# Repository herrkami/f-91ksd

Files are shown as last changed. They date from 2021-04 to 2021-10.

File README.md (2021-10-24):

# F-91KSD

F-91KSD is a functional and optical modification of the Casio® F-91W.

**Hardware and firmware are heavily based on the brilliant
[pluto](https://github.com/carrotIndustries/pluto) project.**

## Features
- Multiple chainable countdown timers
- Multiple alarms
- Pulsar app: tap button to measure BPMs and define LED animation
- Consistent and direct user interface
- Three bright LEDs for better readability, blinkiness, and silent alarms
- Stopwatch
- RTTTL ringtones for alarm sounds including some custom sci/fi sounds
- Extensive customisation (key beep frequency and duration, etc.)
- Watch can be calibrated (drift < 1s per month)
- Displays time in decimal/binary/hexadecimal base
- greater than 1 year battery life (estimate based on current consumption)

## Differences to [pluto](https://github.com/carrotIndustries/pluto)
- New PCB (designed in Eagle)
- No compass, no IR receiver, no OTP generation
- Three LEDs including a flash light
- Different menu structure (more Casio-oriented, less menu diving)
- Chainable countdowns
- Optical alarms
- BPM measurement and optical/acoustical metronome
- Some minor bug fixes

## In progress
Battery monitoring isn't functional yet. 

# Credits
Without previous work by [carrotIndustries](https://github.com/carrotIndustries/) and [sh-ow](https://github.com/sh-ow) this project wouldn't exist.
Most of the software components are their work.

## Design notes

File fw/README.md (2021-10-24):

# F-91KSD Firmware
The F-91KSD firmware is based on the [pluto firmware](https://github.com/carrotIndustries/pluto-fw).
It has been forked from its [May 11, 2018 commit state](https://github.com/carrotIndustries/pluto-fw/commit/a3063225761d98f1a0111b59fe00d9e4cfaac7c2).

## Assisted calibration
Aside from being a cool nerd gadget pluto's main purpose is accurately
telling the time. To do so, the RTC needs to be calibrated to
compensate for the crystal's error. To simplify this, the
firmware can now assist the user by keeping track of how long it's been
since the time has last been set. The process goes like this (`acal` in
the time menu):

- **ME**asure: press enter when the minute changs on the reference clock, the time difference will be shown
- **S**econds since **L**ast set: shows how long it's been since the time has been set in units of 100 seconds
- P**PM**: shows the calculated deviation in units of 10ppb, may display "over" when the valued exceeds the displayable range
- **CAL**ibration **st**ore: takes the calculated ppm value, subtracts it from the current calibration value and updates the calibration
- **ADJ**ust: corrects the time by the measured value. Correction only takes place when the correction value can be applied without overflow, PM flashed while correction is pending.

# Architectural overview
To simplify development, the pluto firmware can be compiled to run on
Linux. User interface (LCD screen and buttons) is provided by a Gtk+
application the firmware connects to using a pair of ZeroMQ sockets. In
spite of being technically inaccurate, this mode of operation is called
'simulator'.
This requires dividing the firmware in three layers:

## Hardware Abstraction Layer (hal)
This layer provides the interface to the underlying hardware. Currently, there are HALs for
the MSP430FR6972 target and the simulator running on Linux. Only the hardware-dependent aspects
are implemented here, the hardware-independent aspects are left to the
next layer to avoid code duplication.

## Services (svc)
The services layer implements hardware-independent features like
playing back RTTTL ringtones, providing the LCD character set and
handling menu operation.

## Application (app)
The application layer provides the user interface. Currently, the
application layer is dependent on the F-91W's LCD layout.

# Simulator
As explained earlier, the firmware can be compiled to run on Linux.
This way, the firmware has been developed before the hardware being
available. Not having to fiddle with the tiny watch hardware makes
development of target-independent features much easier as well. To
simplify debugging of the firmware, the user interface consisting of the LCD screen and
buttons runs as a separate process the firmware connects to using a
pair of ZeroMQ sockets. The buzzer is emulated inside of the firmware
itself using a direct digital synthesis approach. To make the emulated
buzzer sound more real, the DDS lookup is rich of odd and even
harmonics. Sound is output using pulseaudio. Primarily due to laziness,
the emulator doesn't support these features :

- setting time/date
- RTC calibration
- persistent settings
- non-constant compass values
- backlight dimming

This list is very likely to be incomplete, nevertheless the simulator
has proven to be quite useful. Obligatory screenshot:
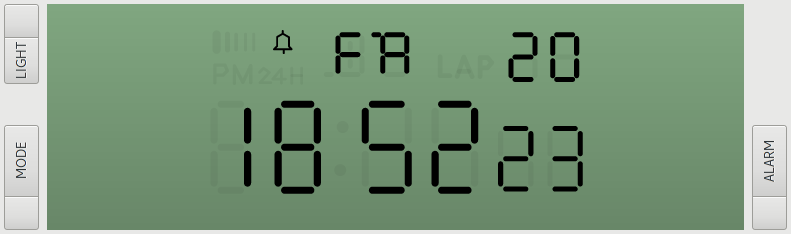
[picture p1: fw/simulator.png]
Simulator GUI


# Target
To conserve power and get anywhere near an acceptable battery life, the
firmware has to make aggressive use of the MSP430 low power features.
Most of the time, the MCU is asleep in LPM3 mode. In this mode, only
the low-frequency clock ACLK (sourced from 32.768 kHz crystal) and
low-power peripherals, like LCD and RTC are active. The MCU gets woken
up by interrupts:

- RTC as 4Hz tick source, used for display updating and time
  base for countdown timers.
- ~100Hz debounce timer: This timer only runs, when the aforementioned
  button polling ISR detects a pressed button.
- 128Hz AUX timer: This timer gets enabled by the services when there's
  need for high-precision timing of events like RTTTL playback or the
  stopwatch.
- 16Hz timer interrupt for button polling: Because of layout
  constraints, the buttons aren't connected to interrupt-capable GPIO
  pins, so this interrupt is used. Since the associated interrupt
  service routine only checks for the state of three GPIO pins, and
  quickly goes back to sleep, its power footprint is negligible.

All ISRs except for the last one exit the low-power mode, so the main
loop will get called.

# Detailed architecture
## HAL
The HAL provides a unified interface to the target's and simulator's
features:
### LCD
The HAL groups the LCD into digits. A digit is either a
7-segment-like digit or a bunch of indicators.
The simulator's HAL sends the segments to be set over to the display
process as a ZeroMQ message. The target has has to use a mapping table
that maps HAL LCD segments to the appropriate COM and SEG lines.
### Other features
The remaining features are pretty mundane, in case you want to
implement a new hal, take a look at common/hal/hal.h to find out what
you need to implement.

## Events
To meet above power requirements, the pluto firmware is event-based.
Once the main loop gets called, it figures out why it's been called and
populates a bitfield typed `svc_main_proc_event_t` accordingly and
hands over to `svc_main_proc`. After handling services-related things
like processing alarms and countdown timers, it'll dispatch the event
to the currently active app.

## Apps, Views and Menus
An app provides a distinct set of features to the users. It doesn't contain any
business logic, that's what the services are for. An app is divided
into multiple views. A view is roughly equivalent to one level in menu
hierarchy. A view's main function may either just call the menu in case
the view offers a constant number of choices to the user or may handle
events and drawing all by itself when more complex interaction is
required. Aside from a list of items, the menu provides a facility for
handling numeric input. To accommodate different use cases, the menu
relies on the application to translate incrementing and decrementing a
single digit into an actual numeric value taking into account clipping
and other constraints.

## LCD
The services layer uses a character table for each kind of LCD digit to
provide the best possible character rendering for each segment. It
provides functions for writing strings and integers to the LCD.

## OTP generation
Right now, the OTP generator is WIP, since there isn't a way to
synchronize the OTP clock and uploading secrets involves taking apart
the watch and flashing the firmware. To protect the OTP secrets,
they're encrypted using the MSP430's built-in AES peripheral. The
key is derived from the 4-digit PIN using the first 128bits of the
PIN's SHA-1 hash. One has to take care to pad the secrets with random
bytes, so that an attacker can't tell whether a PIN is correct or not.
You're welcome to improve the security of the secret storage.

## Persistent settings
Since the MSP430FR6972 uses FRAM for nonvolatile storage, writing
nonvolatile data is as easy as writing to RAM. All nonvolatile
variables are linked into a dedicated section, that can be left
unmodified when updating the firmware. That's what the "program-noload"
target is for. Currently, alarms, countdown timers, OTP secrets and
some settings are stored in nonvolatile memory.

# How do I build?
## Dependencies for both target and simulator
 - python 3 (3.5 tested)
 - python-rtttl for parsing RTTTL ringtones
 - make

## Dependencies for simulator
 - C compiler (gcc tested)
 - zeromq (for communication between firmware and GUI)
 - pulseaudio (for buzzer simulation)
 - mbedtls (for simulating the MSP430's hardware AES)
 - python (GUI)
 - Gtk+ 3 (GUI)
 - pygobject (GUI)

## Dependencies for target
 - msp430-elf toolchain
 - mspdebug for firmware programming

With these dependencies satisfied, the pluto firmware should build on
any reasonably up-to-date Linux distribution.

## Building and running simulator
```
$ cd sim
$ make
$ ./emu.py&
$ ./sim
```

## Building for target
```
$ cd target
$ make
$ make program
```
You may have to modify the Makefile to suit your particular programmer.

# Credits
Without previous work by [carrotIndustries](https://github.com/carrotIndustries/) and [sh-ow](https://github.com/sh-ow) this project wouldn't exist.
Most of the software components is their work.

# Included third-party software
- [mbedtls](https://tls.mbed.org/) SHA-1 for use in HMAC
- [MSP430 driverlib](http://www.ti.com/tool/mspdriverlib) AES256
  peripheral driver
- [liboath](http://www.nongnu.org/oath-toolkit/liboath-api/liboath-oath.html)
  for TOTP generation

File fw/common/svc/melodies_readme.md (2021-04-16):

# RTTTL (Ring Tone Text Transfer Language) format

An RTTTL ring tone can be specified in the following format:
```
<name>:d=<default duration>,o=<default octave>,b=<BPM>:
<duration><pitch><octave>,<duration><pitch><octave>,...
```

For example:
```
fifth:d=4,o=5,b=63:8P,8G5,8G5,8G5,2D#5
```

Allowed durations:
```
1, 2, 4, 8, 16, 32
```

Allowed octaves:
```
4, 5, 6, 7
```

Allowed BPMs:
```
25, 28, 31, 35, 40, 45, 50, 56, 63, 70, 80, 90,
100, 112, 125, 140, 160, 180, 200, 225, 250, 285,
320, 355, 400, 450, 500, 565, 635, 715, 800, 900
```

Allowed pitches:
```
'p', 'c', 'c#', 'd', 'd#', 'e', 'f', 'f#', 'g', 'g#', 'a', 'a#', 'h', 'b'
```

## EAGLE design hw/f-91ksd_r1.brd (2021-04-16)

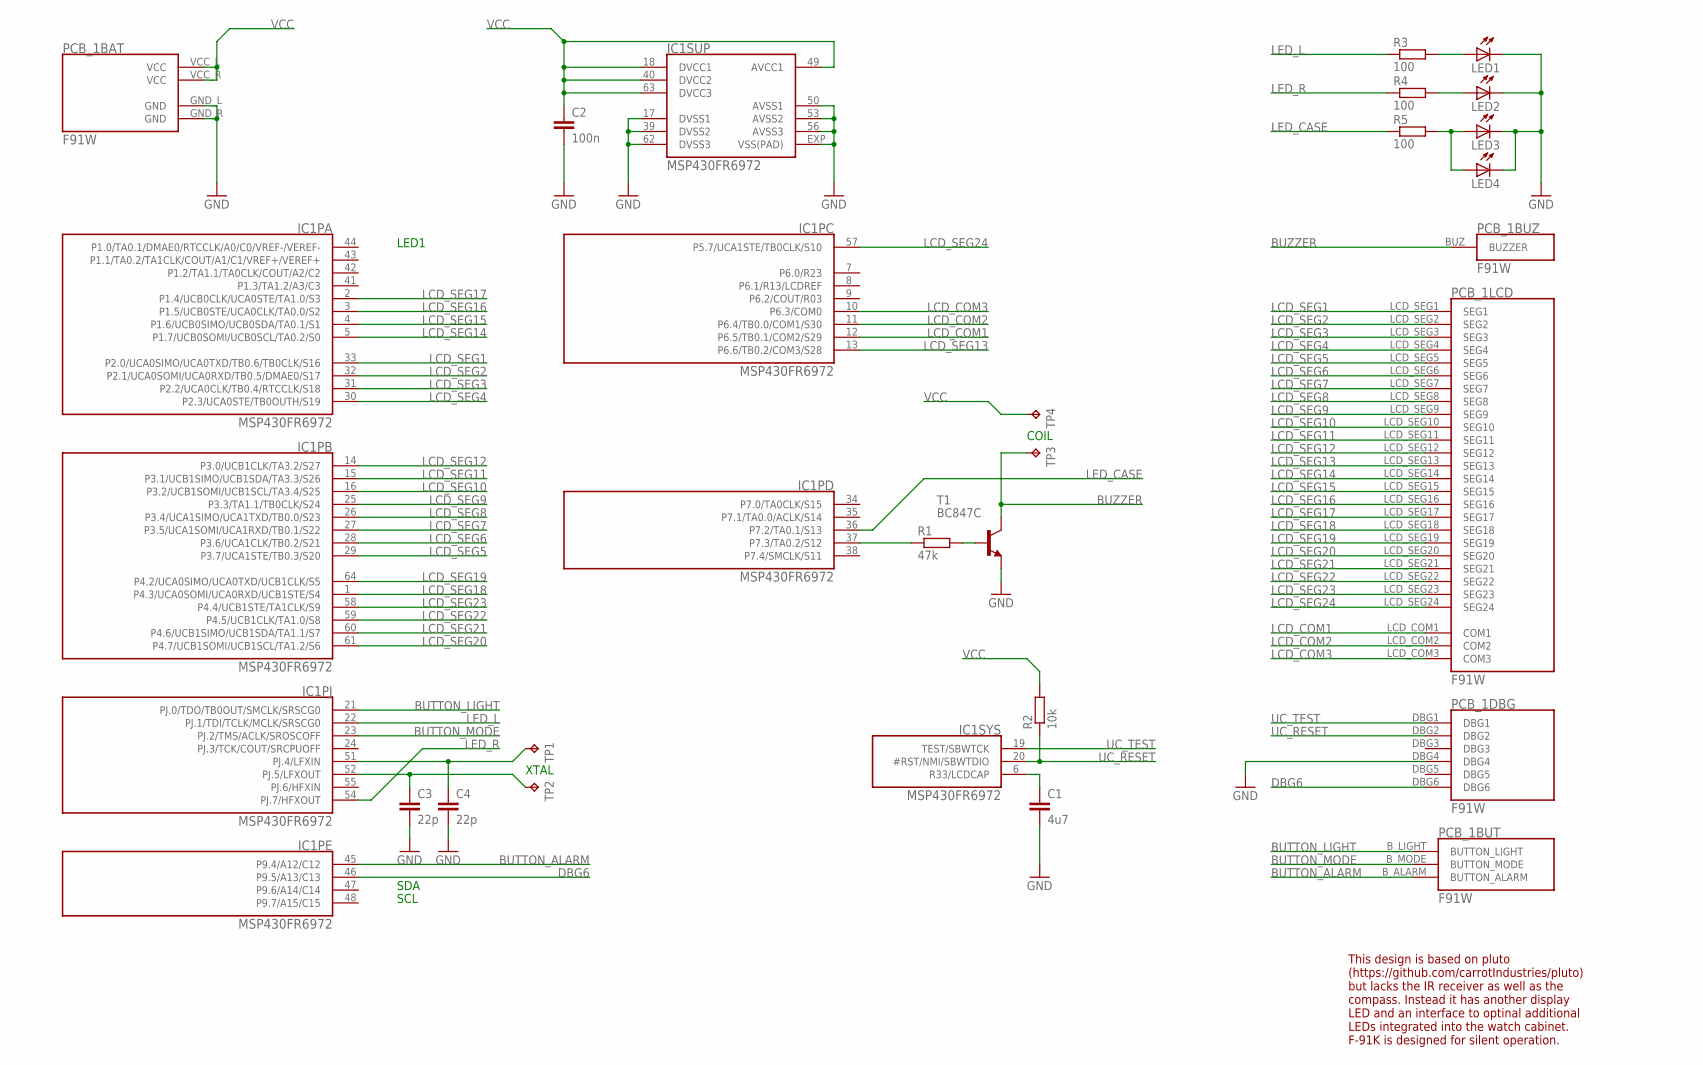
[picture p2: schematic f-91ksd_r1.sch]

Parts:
C1: 4u7; C0603-WW
C2: 100n; C0603-WW
C3, C4: 22p; C0603-WW
IC1: MSP430FR6972; QFN64-9X9
LED1, LED2: LEDCHIPLED_0805; CHIPLED_0805
LED3, LED4: LEDCHIPLED_0603; CHIPLED_0603
PCB_1: F91W
R1: 47k; R0603-WW
R2: 10k; R0603-WW
R3, R4, R5: 100; R0603-WW
T1: BC847C; SOT23-BEC
TP1, TP2: TPTP07SQ; TP07SQ
TP3, TP4: TPTP11SQ; TP11SQ

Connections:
BUTTON_ALARM: IC1.45 (P9.4/A12/C12), PCB_1.B_ALARM (BUTTON_ALARM)
BUTTON_LIGHT: IC1.21 (PJ.0/TDO/TB0OUT/SMCLK/SRSCG0), PCB_1.B_LIGHT (BUTTON_LIGHT)
BUTTON_MODE: IC1.23 (PJ.2/TMS/ACLK/SROSCOFF), PCB_1.B_MODE (BUTTON_MODE)
BUZZER: PCB_1.BUZ (BUZZER), T1.C, TP3.TP
DBG6: IC1.46 (P9.5/A13/C13), PCB_1.DBG6
GND: C1.2, C2.2, C3.2, C4.2, IC1.17 (DVSS1), IC1.39 (DVSS2), IC1.50 (AVSS1), IC1.53 (AVSS2), IC1.56 (AVSS3), IC1.62 (DVSS3), IC1.EXP (VSS(PAD)), LED1.C, LED2.C, LED3.C, LED4.C, PCB_1.DBG4, PCB_1.GND_L (GND), PCB_1.GND_R (GND), T1.E
LCD_COM1: IC1.12 (P6.5/TB0.1/COM2/S29), PCB_1.LCD_COM1 (COM1)
LCD_COM2: IC1.11 (P6.4/TB0.0/COM1/S30), PCB_1.LCD_COM2 (COM2)
LCD_COM3: IC1.10 (P6.3/COM0), PCB_1.LCD_COM3 (COM3)
LCD_SEG1: IC1.33 (P2.0/UCA0SIMO/UCA0TXD/TB0.6/TB0CLK/S16), PCB_1.LCD_SEG1 (SEG1)
LCD_SEG2: IC1.32 (P2.1/UCA0SOMI/UCA0RXD/TB0.5/DMAE0/S17), PCB_1.LCD_SEG2 (SEG2)
LCD_SEG3: IC1.31 (P2.2/UCA0CLK/TB0.4/RTCCLK/S18), PCB_1.LCD_SEG3 (SEG3)
LCD_SEG4: IC1.30 (P2.3/UCA0STE/TB0OUTH/S19), PCB_1.LCD_SEG4 (SEG4)
LCD_SEG5: IC1.29 (P3.7/UCA1STE/TB0.3/S20), PCB_1.LCD_SEG5 (SEG5)
LCD_SEG6: IC1.28 (P3.6/UCA1CLK/TB0.2/S21), PCB_1.LCD_SEG6 (SEG6)
LCD_SEG7: IC1.27 (P3.5/UCA1SOMI/UCA1RXD/TB0.1/S22), PCB_1.LCD_SEG7 (SEG7)
LCD_SEG8: IC1.26 (P3.4/UCA1SIMO/UCA1TXD/TB0.0/S23), PCB_1.LCD_SEG8 (SEG8)
LCD_SEG9: IC1.25 (P3.3/TA1.1/TB0CLK/S24), PCB_1.LCD_SEG9 (SEG9)
LCD_SEG10: IC1.16 (P3.2/UCB1SOMI/UCB1SCL/TA3.4/S25), PCB_1.LCD_SEG10 (SEG10)
LCD_SEG11: IC1.15 (P3.1/UCB1SIMO/UCB1SDA/TA3.3/S26), PCB_1.LCD_SEG11 (SEG11)
LCD_SEG12: IC1.14 (P3.0/UCB1CLK/TA3.2/S27), PCB_1.LCD_SEG12 (SEG12)
LCD_SEG13: IC1.13 (P6.6/TB0.2/COM3/S28), PCB_1.LCD_SEG13 (SEG13)
LCD_SEG14: IC1.5 (P1.7/UCB0SOMI/UCB0SCL/TA0.2/S0), PCB_1.LCD_SEG14 (SEG14)
LCD_SEG15: IC1.4 (P1.6/UCB0SIMO/UCB0SDA/TA0.1/S1), PCB_1.LCD_SEG15 (SEG15)
LCD_SEG16: IC1.3 (P1.5/UCB0STE/UCA0CLK/TA0.0/S2), PCB_1.LCD_SEG16 (SEG16)
LCD_SEG17: IC1.2 (P1.4/UCB0CLK/UCA0STE/TA1.0/S3), PCB_1.LCD_SEG17 (SEG17)
LCD_SEG18: IC1.1 (P4.3/UCA0SOMI/UCA0RXD/UCB1STE/S4), PCB_1.LCD_SEG18 (SEG18)
LCD_SEG19: IC1.64 (P4.2/UCA0SIMO/UCA0TXD/UCB1CLK/S5), PCB_1.LCD_SEG19 (SEG19)
LCD_SEG20: IC1.61 (P4.7/UCB1SOMI/UCB1SCL/TA1.2/S6), PCB_1.LCD_SEG20 (SEG20)
LCD_SEG21: IC1.60 (P4.6/UCB1SIMO/UCB1SDA/TA1.1/S7), PCB_1.LCD_SEG21 (SEG21)
LCD_SEG22: IC1.59 (P4.5/UCB1CLK/TA1.0/S8), PCB_1.LCD_SEG22 (SEG22)
LCD_SEG23: IC1.58 (P4.4/UCB1STE/TA1CLK/S9), PCB_1.LCD_SEG23 (SEG23)
LCD_SEG24: IC1.57 (P5.7/UCA1STE/TB0CLK/S10), PCB_1.LCD_SEG24 (SEG24)
LED_CASE: IC1.36 (P7.2/TA0.1/S13), R5.1
LED_L: IC1.22 (PJ.1/TDI/TCLK/MCLK/SRSCG0), R3.1
LED_R: IC1.54 (PJ.7/HFXOUT), R4.1
unnamed: C1.1, IC1.6 (R33/LCDCAP)
unnamed: IC1.37 (P7.3/TA0.2/S12), R1.1
unnamed: C4.1, IC1.51 (PJ.4/LFXIN), TP1.TP
unnamed: C3.1, IC1.52 (PJ.5/LFXOUT), TP2.TP
unnamed: R1.2, T1.B
unnamed: LED3.A, LED4.A, R5.2
unnamed: LED1.A, R3.2
unnamed: LED2.A, R4.2
UC_RESET: IC1.20 (#RST/NMI/SBWTDIO), PCB_1.DBG2, R2.1
UC_TEST: IC1.19 (TEST/SBWTCK), PCB_1.DBG1
VCC: C2.1, IC1.18 (DVCC1), IC1.40 (DVCC2), IC1.49 (AVCC1), IC1.63 (DVCC3), PCB_1.VCC_L (VCC), PCB_1.VCC_R (VCC), R2.2, TP4.TP

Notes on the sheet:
SDA
SCL
LED1
XTAL
COIL
This design is based on pluto (https://github.com/carrotIndustries/pluto) but lacks the IR receiver as well as the compass. Instead it has another display LED and an interface to optinal additional LEDs integrated into the watch cabinet. F-91K is designed for silent operation.

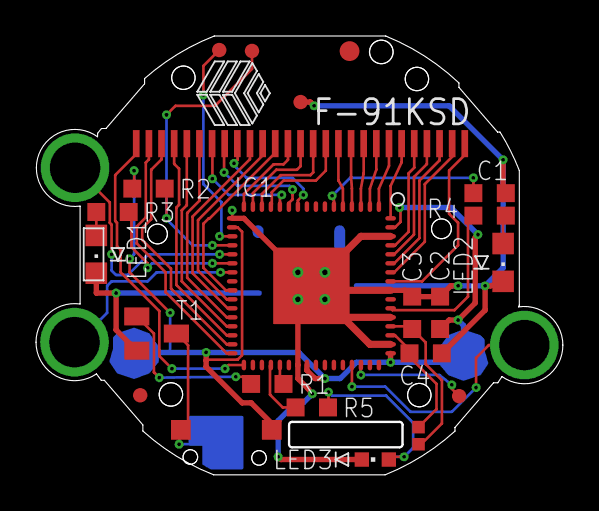
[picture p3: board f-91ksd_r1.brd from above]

Board: 2 copper layers, 29.3 x 24.4 mm, 20 parts (1 on the bottom side), 47 nets.

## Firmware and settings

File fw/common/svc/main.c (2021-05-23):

#include "svc.h"
#include "aux_timer.h"
#include "common/app/app.h"
#include "common/hal/hal.h"
#include "common/hal/lcd_segments.h"
#include <unistd.h>
#include <stdio.h>

void svc_main_proc(svc_main_proc_event_t event) {
	static uint8_t keypress;
	if(event & (SVC_MAIN_PROC_EVENT_KEY_ANY | SVC_MAIN_PROC_EVENT_KEY_ANY_LONG)) {
		if(svc_alarm_get_pending() || svc_countdown_get_pending()) {
			// eat event if alarm/countdown shall be disabled
			event &= ~(SVC_MAIN_PROC_EVENT_KEY_ANY | SVC_MAIN_PROC_EVENT_KEY_ANY_LONG);
			svc_pulsar_stop();
		}
		svc_alarm_clear_pending();
		svc_countdown_clear_pending();
		keypress = 1;
		svc_beep_key();
		svc_flash_rightled_key();
	}
	if(event & SVC_MAIN_PROC_EVENT_AUX_TIMER) {
		svc_aux_timer_handler();
	}
	if(svc_backlight_process(event)) {
		// eat event if flashlight shall be disabled
		event &= ~(SVC_MAIN_PROC_EVENT_KEY_ANY | SVC_MAIN_PROC_EVENT_KEY_ANY_LONG);
	}
	if(event & SVC_MAIN_PROC_EVENT_TICK) {
		static uint8_t div;
		if(!div) { /* prescale to one second */
			svc_countdown_process();
			svc_seconds_since_last_set_process();
			svc_menu_process_timetohome(keypress);
			keypress = 0;
		}
		div = (div+1)%4;

		svc_lcd_blink_process();
		svc_rtc_adj_process();
	}
	if(!(event & SVC_MAIN_PROC_EVENT_AUX_TIMER) || svc_aux_timer_get_call_main()) {
		app_current_update();
		hal_lcd_set_mode(HAL_LCD_MODE_BUFFERED);
		if(app_view_changed) {
			if(app_current->views[app_current->priv->view_current].enter) {
				app_current->views[app_current->priv->view_current].enter(app_current->priv->view_current, app_current);
				app_view_changed = 0;
			}
		}
		app_current->views[app_current->priv->view_current].main(app_current->priv->view_current, app_current, event);
	}

	if(svc_chro_get_any_running()) {
		hal_lcd_seg_set(HAL_LCD_SEG_LAP, 1);
		hal_lcd_seg_set_blink(HAL_LCD_SEG_LAP, 1);
	}
	svc_alarm_process();
	if(svc_alarm_get_any_enabled()) {
		hal_lcd_seg_set(HAL_LCD_SEG_BELL, 1);
		hal_lcd_seg_set_blink(HAL_LCD_SEG_BELL, svc_alarm_get_pending());
	}
	else {
		hal_lcd_seg_set(HAL_LCD_SEG_BELL, 0);
	}

	if(svc_countdowns_are_running() || svc_countdown_get_pending()) {
		hal_lcd_seg_set(HAL_LCD_SEG_BARS, 1);
		hal_lcd_seg_set_blink(HAL_LCD_SEG_BARS, svc_countdown_get_pending());
		// hal_lcd_seg_set_blink(HAL_LCD_SEG_BARS, 1);
	}
	else {
		hal_lcd_seg_set(HAL_LCD_SEG_BARS, 0);
	}

	if(svc_rtc_adj_get_pending()) {
		hal_lcd_seg_set(HAL_LCD_SEG_PM, 1);
		hal_lcd_seg_set_blink(HAL_LCD_SEG_PM, 1);
	}
	else {
		hal_lcd_seg_set(HAL_LCD_SEG_PM, 0);
	}

	if(event & SVC_MAIN_PROC_EVENT_TICK) {
		svc_countdown_draw_popup();
		svc_alarm_draw_popup();
	}

	svc_beep_hour();
	svc_flash_caseled_minute();
}

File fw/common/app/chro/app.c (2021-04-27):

#include "common/app/app.h"
#include "common/app/apps.h"
#include "common/svc/svc.h"
#include "common/hal/hal.h"
#include "common/hal/lcd_segments.h"

typedef struct {
	APP_PRIV_COMMON
} priv_t;

#define PRIV(a) ((priv_t*)((a)->priv))

static void main(uint8_t view, const app_t *app, svc_main_proc_event_t event) {
	hal_lcd_clear();
	svc_chro_t ch;
	svc_chro_get(0, &ch);
	svc_chro_convert(&ch);
	svc_chro_state_t st = svc_chro_get_state(0);
	if(event & SVC_MAIN_PROC_EVENT_KEY_ENTER) {
		switch(st) {
			case SVC_CHRO_STATE_RUN :
				svc_chro_hold(0);
			break;

			case SVC_CHRO_STATE_HOLD :
			case SVC_CHRO_STATE_STOP :
				svc_chro_start(0);
			break;
		}
	}
	// else if(event & SVC_MAIN_PROC_EVENT_KEY_DOWN) {
	else if(event & SVC_MAIN_PROC_EVENT_KEY_UP) {
		switch(st) {
			case SVC_CHRO_STATE_RUN :
			case SVC_CHRO_STATE_HOLD :
				svc_chro_stop(0);
			break;

			case SVC_CHRO_STATE_STOP :
				svc_chro_reset(0);
			break;
		}

	}
	// else if(event & SVC_MAIN_PROC_EVENT_KEY_UP) {
	else if(event & SVC_MAIN_PROC_EVENT_KEY_DOWN) {
		// app_exit();
		app_launch(&app_app_pulsar);
	}
	else if(event & SVC_MAIN_PROC_EVENT_KEY_DOWN_LONG) {
		// app_exit();
		app_launch(&app_app_time);
	}

	switch(st) {
		case SVC_CHRO_STATE_RUN :
			svc_lcd_puts(8, "ru");

		break;

		case SVC_CHRO_STATE_HOLD :
			svc_lcd_puts(8, "hl");
		break;

		case SVC_CHRO_STATE_STOP :
			svc_lcd_puts(8, "st");
		break;
	}
	svc_lcd_puti(0, 2, ch.min);
	svc_lcd_puti(2, 2, ch.sec);
	svc_lcd_puti(4, 2, ch.subsec);
	hal_lcd_seg_set(HAL_LCD_SEG_COLON, 1);
	hal_lcd_seg_set_blink(HAL_LCD_SEG_COLON, st==SVC_CHRO_STATE_RUN);

}

static app_view_t view = {
	.main = main
};

static priv_t priv = {0};

const app_t app_app_chro = {
	.n_views = 1,
	.priv = (app_priv_t*)(&priv),
	.views = &view
};

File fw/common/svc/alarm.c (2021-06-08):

#include "alarm.h"
#include "melody.h"
#include "pulsar.h"
#include "common/hal/hal.h"
#include "lcd.h"
#include "common/hal/lcd_segments.h"
#include <string.h>
#include "platform.h"
#define N_ALARMS 11

static svc_alarm_t SECTION_INFOMEM svc_alarms[N_ALARMS] = {
	{.h=8, .m=15, .days=SVC_WEEKDAY_MO, .enable=0, .pulsar=0, .melody=10},
	{.h=11, .m=02, .days=SVC_WEEKDAY_TH, .enable=0, .pulsar=0, .melody=10},
	{.h=6, .m=0, .days=0xff, .enable=0},
	{.h=7, .m=0, .days=0xff, .enable=0},
	{.h=8, .m=0, .days=0xff, .enable=0},
	{.h=9, .m=0, .days=0xff, .enable=0},
	{.h=10, .m=0, .days=0xff, .enable=0},
	{.h=11, .m=0, .days=0xff, .enable=0},
	{.h=12, .m=0, .days=0xff, .enable=0},
	{.h=13, .m=0, .days=0xff, .enable=0},
	{.h=14, .m=0, .days=0xff, .enable=0},

};
const uint8_t svc_alarms_n = N_ALARMS;

typedef enum {
	AF_ENABLED = (1<<0),
	AF_PENDING = (1<<1),
} alarm_flag_t;

static alarm_flag_t alarm_flags = 0;
static uint8_t alarm_pending;

void svc_alarm_get(uint8_t index, svc_alarm_t *out) {
	memcpy(out, &(svc_alarms[index]), sizeof(svc_alarm_t));
}

void svc_alarm_set_time(uint8_t index, uint8_t h, uint8_t m) {
	svc_alarms[index].h = h;
	svc_alarms[index].m = m;
}

void svc_alarm_set_enable(uint8_t index, uint8_t enable) {
	svc_alarms[index].enable = !!enable;
	alarm_flags &= ~AF_ENABLED;
	for(uint8_t i=0; i<svc_alarms_n; i++) {
		if(svc_alarms[i].enable) {
			alarm_flags |= AF_ENABLED;
		}
	}
}

void svc_alarm_set_day(uint8_t index, uint8_t day, uint8_t enable) {
	if(enable) {
		svc_alarms[index].days |= (1<<day);
	}
	else {
		svc_alarms[index].days &= ~(1<<day);
	}
}

void svc_alarm_set_melody(uint8_t index, uint8_t melody) {
	svc_alarms[index].melody = melody;
}

void svc_alarm_set_pulsar(uint8_t index, uint8_t pulsar) {
	svc_alarms[index].pulsar = pulsar;
}

void svc_alarm_set_metronome(uint8_t index, uint8_t state) {
	svc_alarms[index].metronome = state;
}

uint8_t svc_alarm_get_any_enabled(void) {
	return !!(alarm_flags & AF_ENABLED);
}

uint8_t svc_alarm_get_pending(void) {
	return !!(alarm_flags & AF_PENDING);
}

void svc_alarm_clear_pending(void) {
	alarm_flags &= ~AF_PENDING;
}

void svc_alarm_init(void) {
	alarm_flags &= ~AF_ENABLED;
	for(uint8_t i=0; i<svc_alarms_n; i++) {
		// svc_alarms[i].melody = svc_default_melody_get();
		// svc_alarms[i].pulsar = svc_default_pulsar_get();
		if(svc_alarms[i].enable) {
			alarm_flags |= AF_ENABLED;
		}
	}
}

static uint8_t svc_alarm_match(svc_alarm_t *al, hal_rtc_timedate_t *td) {
	return (al->enable) && (al->h == td->h) && (al->m == td->m) && (al->days & (1<<td->dow));
}

void svc_alarm_process(void) {
	static uint8_t min_last = 255;

	hal_rtc_timedate_t td;
	hal_rtc_get(&td);

	if(td.m != min_last) {
		for(uint8_t i=0; i<svc_alarms_n; i++) {
			if(svc_alarm_match(&(svc_alarms[i]), &td)) {
				svc_pulsar_bp_metronome_set_enable(svc_alarms[i].metronome);
				svc_melody_play_repeat(
					svc_alarms[i].melody, svc_melody_alarm_repetitions_get());
				svc_pulsar_play_repeat(
					svc_alarms[i].pulsar, svc_pulsar_alarm_repetitions_get());
				alarm_flags |= AF_PENDING;
				alarm_pending = i;
			}
		}
		min_last = td.m;
	}
}

void svc_alarm_draw_popup(void) {
	static uint8_t div;
	if(alarm_flags & AF_PENDING) {
		if(div < 4) {
			hal_lcd_seg_set(HAL_LCD_SEG_COLON, 0);
			svc_lcd_puts(0, "alrm");
			svc_lcd_puti(4, 2, alarm_pending);
			svc_lcd_force_redraw();
		}

	}
	div = (div+1)%8;
}

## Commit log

2021-04-16 Change directory structure and add hardware design files
    [f-91k.brd, f-91k.sch, f-91ksd_r0.brd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]
2021-04-16 Add service routine modifications for chaining mode to countdown timers
2021-04-17 Implement menu for timer chaining
2021-04-17 Make menu headers blinking, add silent melody, and remove print commands from emulator
2021-04-18 Add pause to timers
2021-04-21 Add MCU/simulation compiler flag for default LED on duration
2021-04-23 Extend short LED flashes to become visible in emulator
    [leds.c]
2021-04-24 Workaround missing tap bug in pulsar
    [app.c]
2021-04-24 Fix pulsar tap miss
    [adjt.c, main.c]
2021-04-27 Add soft PWM backlight routine
2021-05-09 Set standard GTK version to 3.0 and fix pulsar sequence adjustments
    [edit.c]
2021-05-09 Make long menu button press always a leaving event and remove OTP
2021-05-19 Limit brightness levels to 4 stages and change some default parameters
2021-05-19 Improve timer popup notification
2021-05-24 Fix flashlight and return consistency
    [adjt.c, menu.c]
2021-05-26 Add special function to alarm app that sets the current time and day of the week as alarm
2021-05-26 Make led routine more efficient
2021-05-27 Add alarm- and timer-specific metronome enable option
2021-06-08 Fix more-than-eight-timers bug
2021-06-11 Change timer default values
2021-10-24 Add battery monitoring
2021-10-24 Add note about battery monitoring
